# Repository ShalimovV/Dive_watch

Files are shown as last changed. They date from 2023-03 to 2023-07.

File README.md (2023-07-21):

# Dive_watch
DIY dive computer project for free diving

KiCAD project - https://github.com/ShalimovV/Dive_watch/tree/main/Hardware/d_watch_v2

Source code are here - https://github.com/ShalimovV/d_watch_v2_wb55

Youtube - https://www.youtube.com/@ShalimovProjects

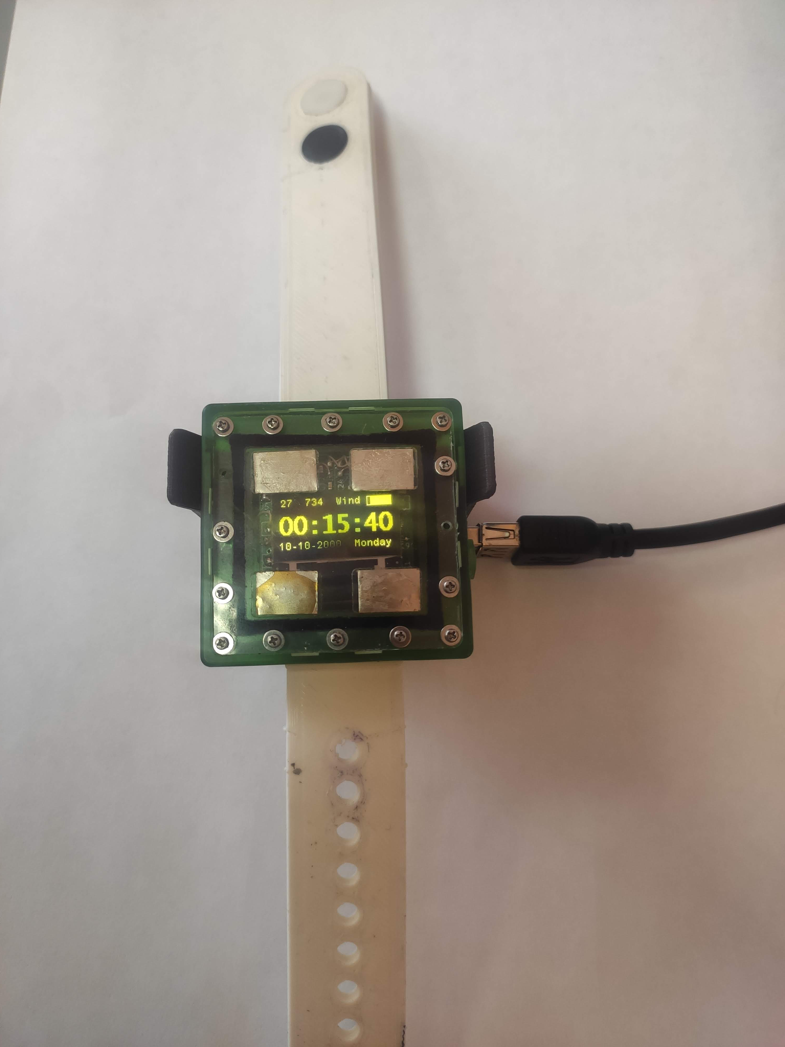
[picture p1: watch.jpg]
Watch


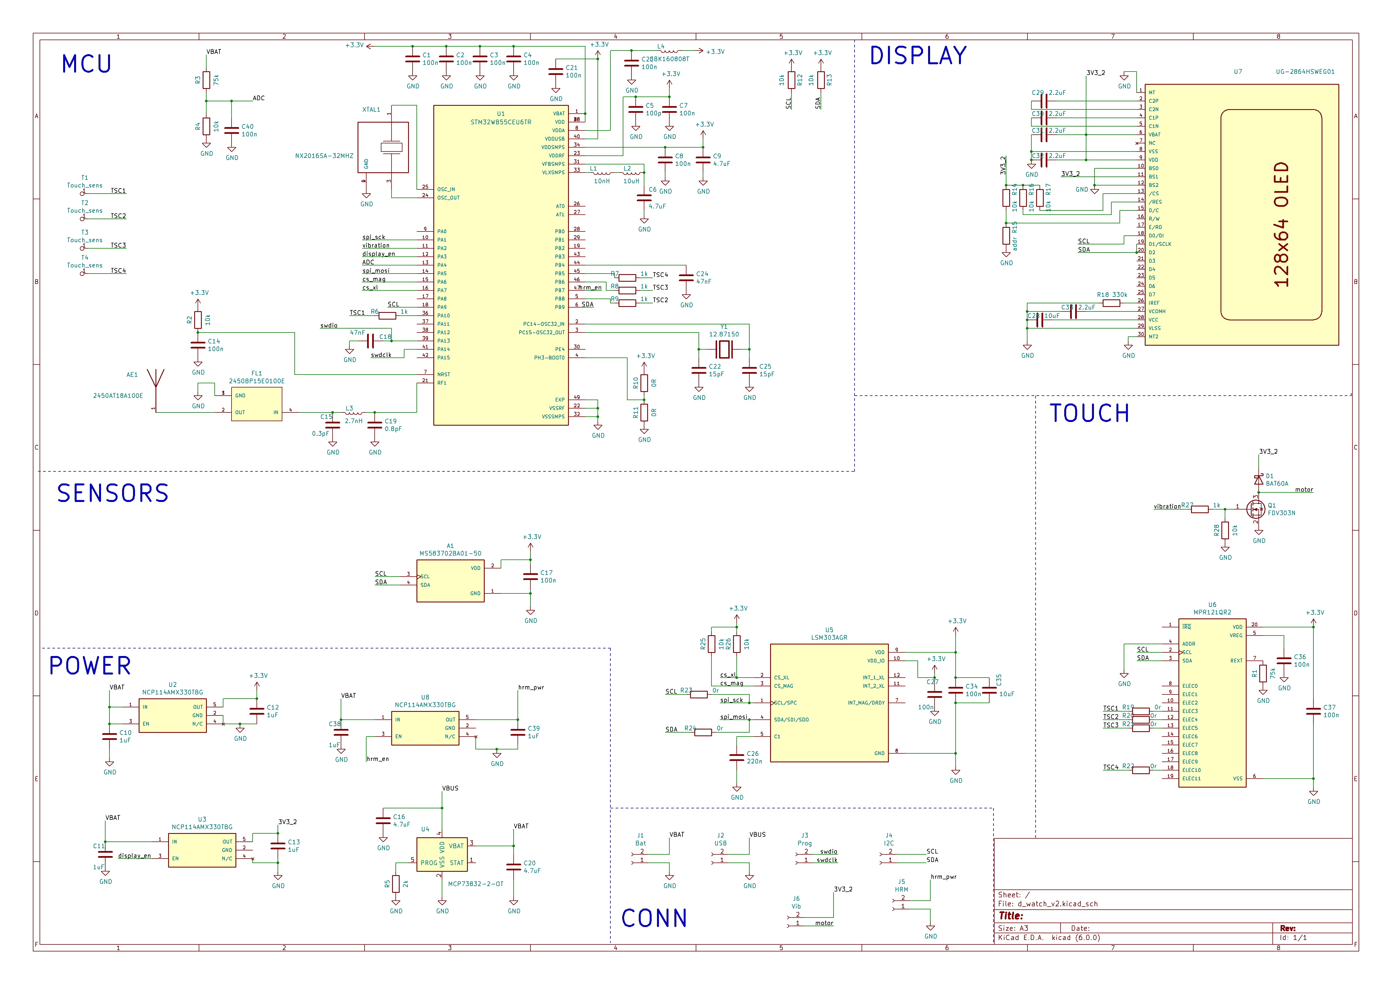
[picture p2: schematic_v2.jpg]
Schematics of watch


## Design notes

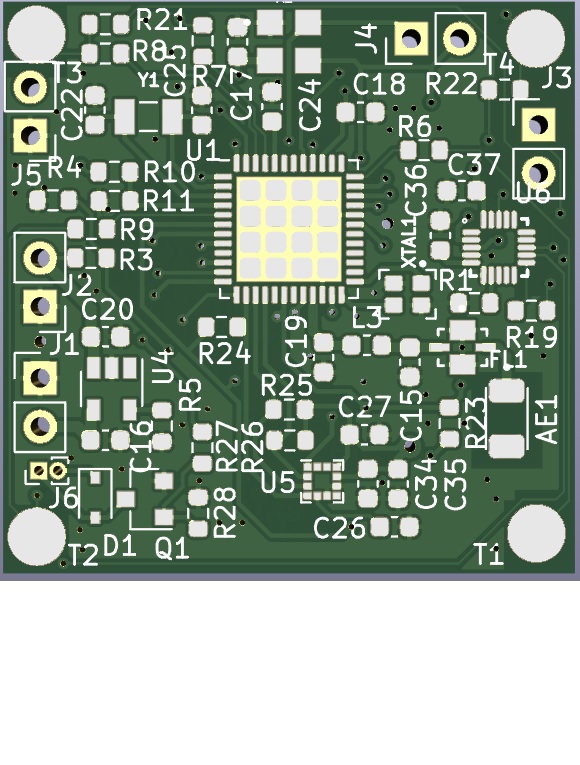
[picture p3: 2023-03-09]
pcb.jpg

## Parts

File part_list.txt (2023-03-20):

				IC
STM32WB55CGU6		UFQFPN48 7x7mm		1pcs		https://aliexpress.ru/item/1005002719693857.html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
MS5837									1pcs		https://aliexpress.ru/item/32965750576.html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
MPR121				QFN20				1pcs		https://aliexpress.ru/item/32821362153.html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
LSM303AGR			LGA-12				1pcs
MCP73831			SOT23-5				1pcs		https://aliexpress.ru/item/32825743634.html?spm=a2g2w.orderdetail.0.0.4e324aa6s5AVtw&sku_id=64850715808
NCP114AMX330T		SOT23-5				3pcs						
Display				128x64OLED			1pcs		https://aliexpress.ru/item/32830523451.html?sku_id=66632198948&spm=.search_results.0.50534aa68fm6GY

			Transistors
2N7002				SOT23				1pcs		https://aliexpress.ru/item/32475575705.html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

			Diode
BAT60A				SOD-323				1pcs		https://aliexpress.ru/item/32962432486.html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

			Resistors								https://aliexpress.ru/item/32773409942.html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
10k					R0603				9pcs
0R					R0603				8pcs
75k					R0603				1pcs
330k				R0603				2pcs
2k					R0603				1pcs
1k					R0603				4pcs
4k7					R0603				4pcs

			Capcitors								https://aliexpress.ru/item/4001345918046.html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
100n				C0603				15pcs
10uF				C0603				2pcs
220n				C0603				1pcs
100p				C0603				1pcs
12.5p				C0603				2pcs
4.7uF				C0603				4pcs
1uF					C0603				4pcs
0.3pF				C0603				1pcs
47nF				C0603				2pcs
0.8pF				C0603				1pcs
2.2uF				C0603				5pcs

			Inductions								https://aliexpress.ru/item/32855637642.html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
10nH				L0603				1pcs
10mH				L0603				1pcs
GBK160808T			L0603				1pcs
2.7nH				L0603				1pcs
2450BP15E0100E							1pcs		https://aliexpress.ru/item/32815857347.html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

			Crystal resonators
32768Hz				XTAL_12.87150		1pcs		https://aliexpress.ru/item/32991925425.html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
NX2016SA-32MHZ		OSCCC200X160X50N	1pcs		https://aliexpress.ru/item/1005002427704043.html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

Chip antenna		2450AT18A100E		1pcs		https://aliexpress.ru/item/4000604209164.html?spm=a2g2w.detail.pers_rcmd.9.141e5b12oDna1O&_evo_buckets=165609,165598,194275&sku_id=10000003837091303&gps-id=pcDetailBottomMoreOtherSeller&scm=1007.14452.331080.0&scm_id=1007.14452.331080.0&scm-url=1007.14452.331080.0&pvid=492aa6b8-92af-4c68-9dc5-84e5a704b253&_t=gps-id:pcDetailBottomMoreOtherSeller,scm-url:1007.14452.331080.0,pvid:492aa6b8-92af-4c68-9dc5-84e5a704b253,tpp_buckets:4452%230%23331080%230_4452%233474%2315675%23136_4452%234862%2324463%23909_4452%233098%239599%23202_4452%235105%2323438%23899_4452%233564%2316062%23650_21387%230%23330480%232_21387%239507%23434562%237_21387%2314793%23456925%234_24525%230%23331148%2318

Vibro motor								1pcs		https://aliexpress.ru/item/4000002321519.html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

Wire												https://aliexpress.ru/item/1005001386328055.html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

Li-Ion Battery										https://aliexpress.ru/item/4001240958438.html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

Rivets												https://aliexpress.ru/item/32998928980.html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

Test pin											https://aliexpress.ru/item/33004747616.html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

Nickel Sheet Plate	8mm								https://aliexpress.ru/item/1005004371792191.html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

ST-Link V2											https://aliexpress.ru/item/32792513237.html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

Screws M1.4x10			16pcs						https://aliexpress.ru/item/10000181324125.html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

Brass insert nut M1.4	16pcs						https://aliexpress.ru/item/1005002181788783.html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,165598,194275&sku_id=12000018969492937&gps-id=pcDetailBottomMoreOtherSeller&scm=1007.34525.331148.0&scm_id=1007.34525.331148.0&scm-url=1007.34525.331148.0&pvid=f5fdbbbf-246d-4539-a032-dc8f5a3d2d5d&_t=gps-id:pcDetailBottomMoreOtherSeller,scm-url:1007.34525.331148.0,pvid:f5fdbbbf-246d-4539-a032-dc8f5a3d2d5d,tpp_buckets:24525%230%23331148%2318_21387%230%23330480%231_21387%239507%23434562%237_21387%2314793%23456925%234_4452%230%23331080%230_4452%233474%2315675%23136_4452%234862%2324463%23909_4452%233098%239599%23202_4452%235105%2323438%23899_4452%233564%2316062%23650&ru_algo_pv_id=f5fdbbbf-246d-4539-a032-dc8f5a3d2d5d&scenario=pcDetailBottomMoreOtherSeller&tpp_rcmd_bucket_id=331148&traffic_source=recommendation

Washer 2mm				16pcs						https://aliexpress.ru/item/32975752411.html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

Acrylic Sheet 			3mm							https://aliexpress.ru/item/32833660352.html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

Rubber Sheet			3mm							https://aliexpress.ru/item/20000002492440.html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
	
Sealer (shaper pads) Victor Reinz 703141410			https://aliexpress.ru/item/1005004584983004.html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

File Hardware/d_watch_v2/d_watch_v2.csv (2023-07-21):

Source: | \\10.97.63.1\c$\Users\shalimov\Dropbox\Work\projects\diving watch\d_watch_v2\d_watch_v2\d_watch_v2.sch
Date: | 14.01.2022 15:19:52
Tool: | Eeschema (5.1.12)-1
Generator: | C:\Program Files\KiCad\bin\scripting\plugins/bom_csv_grouped_by_value.py
Component Count: | 99
Individual Components:
Item | Qty | Reference(s) | Value | LibPart | Footprint | Datasheet | AVAILABILITY | Availability | Comment | DESCRIPTION | Description | MANUFACTURER | MAXIMUM_PACKAGE_HEIGHT | MF | MP | PACKAGE | PARTREV | PRICE | PURCHASE-URL | Package | Price | Purchase-URL | STANDARD
 |  | A1 | MS583702BA01-50 | d_watch_v2-rescue:MS583702BA01-50-MS583702BA01-50 | XDCR_MS583702BA01-50 |  |  |  | MS583702BA01-50
 |  | AE1 | 2450AT18A100E | d_watch_v2-rescue:2450AT18A100E-2450AT18A100E | ANTC3216X140N |  |  |  |  |  |  | JOHANSON DESIGN |  |  |  |  | 1.3 |  |  |  |  |  | IPC-7351B
 |  | C1 | 100n | Device:C | Capacitor_SMD:C_0603_1608Metric | ~
 |  | C2 | 100n | Device:C | Capacitor_SMD:C_0603_1608Metric | ~
 |  | C3 | 100n | Device:C | Capacitor_SMD:C_0603_1608Metric | ~
 |  | C4 | 100n | Device:C | Capacitor_SMD:C_0603_1608Metric | ~
 |  | C5 | 100p | Device:C | Capacitor_SMD:C_0603_1608Metric | ~
 |  | C6 | 4.7uF | Device:C | Capacitor_SMD:C_0603_1608Metric | ~
 |  | C7 | 100n | Device:C | Capacitor_SMD:C_0603_1608Metric | ~
 |  | C8 | 100n | Device:C | Capacitor_SMD:C_0603_1608Metric | ~
 |  | C9 | 4.7uF | Device:C | Capacitor_SMD:C_0603_1608Metric | ~
 |  | C10 | 1uF | Device:C | Capacitor_SMD:C_0603_1608Metric | ~
 |  | C11 | 1uF | Device:C | Capacitor_SMD:C_0603_1608Metric | ~
 |  | C12 | 1uF | Device:C | Capacitor_SMD:C_0603_1608Metric | ~
 |  | C13 | 1uF | Device:C | Capacitor_SMD:C_0603_1608Metric | ~
 |  | C14 | 100n | Device:C | Capacitor_SMD:C_0603_1608Metric | ~
 |  | C15 | 0.3pF | Device:C | Capacitor_SMD:C_0603_1608Metric | ~
 |  | C16 | 4.7uF | Device:C | Capacitor_SMD:C_0603_1608Metric | ~
 |  | C17 | 100n | Device:C | Capacitor_SMD:C_0603_1608Metric | ~
 |  | C18 | 47nF | Device:C | Capacitor_SMD:C_0603_1608Metric | ~
 |  | C19 | 0.8pF | Device:C | Capacitor_SMD:C_0603_1608Metric | ~
 |  | C20 | 4.7uF | Device:C | Capacitor_SMD:C_0603_1608Metric | ~
 |  | C21 | 100n | Device:C | Capacitor_SMD:C_0603_1608Metric | ~
 |  | C22 | 15pF | Device:C | Capacitor_SMD:C_0603_1608Metric | ~
 |  | C23 | 100n | Device:C | Capacitor_SMD:C_0603_1608Metric | ~
 |  | C24 | 47nF | Device:C | Capacitor_SMD:C_0603_1608Metric | ~
 |  | C25 | 15pF | Device:C | Capacitor_SMD:C_0603_1608Metric | ~
 |  | C26 | 220n | Device:C | Capacitor_SMD:C_0603_1608Metric | ~
 |  | C27 | 100n | Device:C | Capacitor_SMD:C_0603_1608Metric | ~
 |  | C28 | 10uF | Device:C | Capacitor_SMD:C_0603_1608Metric | ~
 |  | C29 | 2.2uF | Device:C | Capacitor_SMD:C_0603_1608Metric | ~
 |  | C30 | 2.2uF | Device:C | Capacitor_SMD:C_0603_1608Metric | ~
 |  | C31 | 2.2uF | Device:C | Capacitor_SMD:C_0603_1608Metric | ~
 |  | C32 | 2.2uF | Device:C | Capacitor_SMD:C_0603_1608Metric | ~
 |  | C33 | 2.2uF | Device:C | Capacitor_SMD:C_0603_1608Metric | ~
 |  | C34 | 100n | Device:C | Capacitor_SMD:C_0603_1608Metric | ~
 |  | C35 | 10uF | Device:C | Capacitor_SMD:C_0603_1608Metric | ~
 |  | C36 | 100n | Device:C | Capacitor_SMD:C_0603_1608Metric | ~
 |  | C37 | 100n | Device:C | Capacitor_SMD:C_0603_1608Metric | ~
 |  | C38 | 1uF | Device:C | Capacitor_SMD:C_0603_1608Metric | ~
 |  | C39 | 1uF | Device:C | Capacitor_SMD:C_0603_1608Metric | ~
 |  | C40 | 100n | Device:C | Capacitor_SMD:C_0603_1608Metric | ~
 |  | C41 | 15pF | Device:C | Capacitor_SMD:C_0603_1608Metric | ~
 |  | C42 | 15pF | Device:C | Capacitor_SMD:C_0603_1608Metric | ~
 |  | D1 | BAT60A | Diode:BAT60A | Diode_SMD:D_SOD-323 | https://www.infineon.com/dgdl/Infineon-BAT60ASERIES-DS-v01_01-en.pdf?fileId=db3a304313d846880113def70c9304a9
 |  | FL1 | LFB212G45SG8C341 | d_watch_v2-rescue:LFB212G45SG8C341-LFB212G45SG8C341 | FIL_LFB212G45SG8C341 |  |  |  |  |  |  | Murata | 1.05 mm |  |  |  | N/A |  |  |  |  |  | Manufacturer recommendation
 |  | J1 | Conn_01x02 | Connector:Conn_01x02_Female | Connector_PinHeader_2.54mm:PinHeader_1x02_P2.54mm_Vertical | ~
 |  | J2 | Conn_01x02 | Connector:Conn_01x02_Female | Connector_PinHeader_2.54mm:PinHeader_1x02_P2.54mm_Vertical | ~
 |  | J3 | Conn_01x02 | Connector:Conn_01x02_Female | Connector_PinHeader_2.54mm:PinHeader_1x02_P2.54mm_Vertical | ~
 |  | J4 | Conn_01x02 | Connector:Conn_01x02_Female | Connector_PinHeader_2.54mm:PinHeader_1x02_P2.54mm_Vertical | ~
 |  | J5 | Conn_01x02 | Connector:Conn_01x02_Female | Connector_PinHeader_2.54mm:PinHeader_1x02_P2.54mm_Vertical | ~
 |  | J6 | Conn_01x02 | Connector:Conn_01x02_Female | Connector_PinHeader_1.00mm:PinHeader_1x02_P1.00mm_Vertical | ~
 |  | L1 | 10nH | Device:L | Inductor_SMD:L_0603_1608Metric | ~
 |  | L2 | 10mH | Device:L | Inductor_SMD:L_0603_1608Metric | ~
 |  | L3 | 2.7nH | Device:L | Inductor_SMD:L_0603_1608Metric | ~
 |  | L4 | GBK160808T | Device:L | Inductor_SMD:L_0603_1608Metric | ~
 |  | Q1 | FDV303N | Transistor_FET:2N7002K | Package_TO_SOT_SMD:SOT-23 | https://www.diodes.com/assets/Datasheets/ds30896.pdf
 |  | R1 | 75k | Device:R | Resistor_SMD:R_0603_1608Metric | ~
 |  | R2 | 10k | Device:R | Resistor_SMD:R_0603_1608Metric | ~
 |  | R3 | 330k | Device:R | Resistor_SMD:R_0603_1608Metric | ~
 |  | R4 | 10k | Device:R | Resistor_SMD:R_0603_1608Metric | ~
 |  | R5 | 2k | Device:R | Resistor_SMD:R_0603_1608Metric | ~
 |  | R6 | 1k | Device:R | Resistor_SMD:R_0603_1608Metric | ~
 |  | R7 | 1k | Device:R | Resistor_SMD:R_0603_1608Metric | ~
 |  | R8 | 1k | Device:R | Resistor_SMD:R_0603_1608Metric | ~
 |  | R9 | 1k | Device:R | Resistor_SMD:R_0603_1608Metric | ~
 |  | R10 | 0R | Device:R | Resistor_SMD:R_0603_1608Metric | ~
 |  | R11 | 0R | Device:R | Resistor_SMD:R_0603_1608Metric | ~
 |  | R12 | 10k | Device:R | Resistor_SMD:R_0603_1608Metric | ~
 |  | R13 | 10k | Device:R | Resistor_SMD:R_0603_1608Metric | ~
 |  | R14 | 10k | Device:R | Resistor_SMD:R_0603_1608Metric | ~
 |  | R15 | addr | Device:R | Resistor_SMD:R_0603_1608Metric | ~
 |  | R16 | 10k | Device:R | Resistor_SMD:R_0603_1608Metric | ~
 |  | R17 | 10k | Device:R | Resistor_SMD:R_0603_1608Metric | ~
 |  | R18 | 330k | Device:R | Resistor_SMD:R_0603_1608Metric | ~
 |  | R19 | 0r | Device:R | Resistor_SMD:R_0603_1608Metric | ~
 |  | R20 | 0r | Device:R | Resistor_SMD:R_0603_1608Metric | ~
 |  | R21 | 0r | Device:R | Resistor_SMD:R_0603_1608Metric | ~
 |  | R22 | 0r | Device:R | Resistor_SMD:R_0603_1608Metric | ~
 |  | R23 | 0r | Device:R | Resistor_SMD:R_0603_1608Metric | ~
 |  | R24 | 0r | Device:R | Resistor_SMD:R_0603_1608Metric | ~
 |  | R25 | 10k | Device:R | Resistor_SMD:R_0603_1608Metric | ~
 |  | R26 | 10k | Device:R | Resistor_SMD:R_0603_1608Metric | ~
 |  | R27 | 1k | Device:R | Resistor_SMD:R_0603_1608Metric | ~
 |  | R28 | 10k | Device:R | Resistor_SMD:R_0603_1608Metric | ~
 |  | T1 | Touch_sens | d_watch_v2-rescue:Touch_sens-touch_sens | Sensor:touch_pad
 |  | T2 | Touch_sens | d_watch_v2-rescue:Touch_sens-touch_sens | Sensor:touch_pad
 |  | T3 | Touch_sens | d_watch_v2-rescue:Touch_sens-touch_sens | Sensor:touch_pad
 |  | T4 | Touch_sens | d_watch_v2-rescue:Touch_sens-touch_sens | Sensor:touch_pad
 |  | U1 | STM32WB55CEU6TR | d_watch_v2-rescue:STM32WB55CEU6TR-STM32WB55CEU6TR | Package_DFN_QFN:QFN-48-1EP_7x7mm_P0.5mm_EP5.45x5.45mm |  |  |  |  |  |  | STMicroelectronics | 0.6 mm |  |  |  | 5 |  |  |  |  |  | IPC 7351B
 |  | U4 | MCP73832-2-OT | Battery_Management:MCP73832-2-OT | Package_TO_SOT_SMD:SOT-23-5 | http://ww1.microchip.com/downloads/en/DeviceDoc/20001984g.pdf
 |  | U5 | LSM303AGR | d_watch_v2-rescue:LSM303AGR-LSM303AGR | Package_LGA:LGA-12_2x2mm_P0.5mm |  |  | In Stock |  |  | \nAccelerometer, Magnetometer, Temperature, 6 Axis Sensor I²C, SPI Output\n |  |  | STMicroelectronics | LSM303AGR |  |  |  |  | VFLGA-12 STMicroelectronics | None | https://pricing.snapeda.com/search/part/LSM303AGR/?ref=eda
 |  | U6 | MPR121QR2 | d_watch_v2-rescue:MPR121QR2-MPR121QR2 | QFN40P300X300X60-20N |  |  |  |  |  |  | Freescale NXP
 |  | U7 | UG-2864HSWEG01 | d_watch_v2-rescue:UG-2864HSWEG01-UG-2864HSWEG01 | 1X30-0.7MM
 |  | VR1 | TLV707185DQNR | d_watch_v2-rescue:TLV707185DQNR-TLV707185DQNR | VREG_TLV707185DQNR |  | Warning |  |  | 200-mA, low-IQ, low-dropout voltage regulator with enable 4-X2SON -40 to 125 |  |  |  | Texas Instruments | TLV707185DQNR | X2SON-4 Texas Instruments |  | None | https://pricing.snapeda.com/search/part/TLV707185DQNR/?ref=eda
 |  | VR2 | TLV707185DQNR | d_watch_v2-rescue:TLV707185DQNR-TLV707185DQNR | VREG_TLV707185DQNR |  | Warning |  |  | 200-mA, low-IQ, low-dropout voltage regulator with enable 4-X2SON -40 to 125 |  |  |  | Texas Instruments | TLV707185DQNR | X2SON-4 Texas Instruments |  | None | https://pricing.snapeda.com/search/part/TLV707185DQNR/?ref=eda
 |  | VR3 | TLV707185DQNR | d_watch_v2-rescue:TLV707185DQNR-TLV707185DQNR | VREG_TLV707185DQNR |  | Warning |  |  | 200-mA, low-IQ, low-dropout voltage regulator with enable 4-X2SON -40 to 125 |  |  |  | Texas Instruments | TLV707185DQNR | X2SON-4 Texas Instruments |  | None | https://pricing.snapeda.com/search/part/TLV707185DQNR/?ref=eda
 |  | XTAL1 | NX2016SA-32MHZ | d_watch_v2-rescue:NX2016SA-52MHZ-EXS00A-CS07103-NX2016SA-52MHZ-EXS00A-CS07103 | OSCCC200X160X50N |  |  |  |  |  |  | NDK |  |  |  |  | N/A |  |  |  |  |  | IPC-7351B
 |  | Y1 | 12.87150 | d_watch_v2-rescue:12.87150-12.87150 | XTAL_12.87150 |  |  |  |  |  |  | Geyer Electronic | 0.9mm |  |  |  | 22.06.2021 |  |  |  |  |  | Manufacturer Recommendations
Collated Components:
Item | Qty | Reference(s) | Value | LibPart | Footprint | Datasheet | AVAILABILITY | Availability | Comment | DESCRIPTION | Description | MANUFACTURER | MAXIMUM_PACKAGE_HEIGHT | MF | MP | PACKAGE | PARTREV | PRICE | PURCHASE-URL | Package | Price | Purchase-URL | STANDARD
1 | 1 | A1 | MS583702BA01-50 | d_watch_v2-rescue:MS583702BA01-50-MS583702BA01-50 | XDCR_MS583702BA01-50 |  |  |  | MS583702BA01-50
2 | 1 | AE1 | 2450AT18A100E | d_watch_v2-rescue:2450AT18A100E-2450AT18A100E | ANTC3216X140N |  |  |  |  |  |  | JOHANSON DESIGN |  |  |  |  | 1.3 |  |  |  |  |  | IPC-7351B
3 | 15 | C1, C2, C3, C4, C7, C8, C14, C17, C21, C23, C27, C34, C36, C37, C40 | 100n | Device:C | Capacitor_SMD:C_0603_1608Metric | ~
4 | 1 | C5 | 100p | Device:C | Capacitor_SMD:C_0603_1608Metric | ~
5 | 4 | C6, C9, C16, C20 | 4.7uF | Device:C | Capacitor_SMD:C_0603_1608Metric | ~
6 | 6 | C10, C11, C12, C13, C38, C39 | 1uF | Device:C | Capacitor_SMD:C_0603_1608Metric | ~
7 | 1 | C15 | 0.3pF | Device:C | Capacitor_SMD:C_0603_1608Metric | ~
8 | 2 | C18, C24 | 47nF | Device:C | Capacitor_SMD:C_0603_1608Metric | ~
9 | 1 | C19 | 0.8pF | Device:C | Capacitor_SMD:C_0603_1608Metric | ~
10 | 4 | C22, C25, C41, C42 | 15pF | Device:C | Capacitor_SMD:C_0603_1608Metric | ~
11 | 1 | C26 | 220n | Device:C | Capacitor_SMD:C_0603_1608Metric | ~
12 | 2 | C28, C35 | 10uF | Device:C | Capacitor_SMD:C_0603_1608Metric | ~
13 | 5 | C29, C30, C31, C32, C33 | 2.2uF | Device:C | Capacitor_SMD:C_0603_1608Metric | ~
14 | 1 | D1 | BAT60A | Diode:BAT60A | Diode_SMD:D_SOD-323 | https://www.infineon.com/dgdl/Infineon-BAT60ASERIES-DS-v01_01-en.pdf?fileId=db3a304313d846880113def70c9304a9
15 | 1 | FL1 | LFB212G45SG8C341 | d_watch_v2-rescue:LFB212G45SG8C341-LFB212G45SG8C341 | FIL_LFB212G45SG8C341 |  |  |  |  |  |  | Murata | 1.05 mm |  |  |  | N/A |  |  |  |  |  | Manufacturer recommendation
16 | 5 | J1, J2, J3, J4, J5 | Conn_01x02 | Connector:Conn_01x02_Female | Connector_PinHeader_2.54mm:PinHeader_1x02_P2.54mm_Vertical | ~
17 | 1 | J6 | Conn_01x02 | Connector:Conn_01x02_Female | Connector_PinHeader_1.00mm:PinHeader_1x02_P1.00mm_Vertical | ~
18 | 1 | L1 | 10nH | Device:L | Inductor_SMD:L_0603_1608Metric | ~
19 | 1 | L2 | 10mH | Device:L | Inductor_SMD:L_0603_1608Metric | ~
20 | 1 | L3 | 2.7nH | Device:L | Inductor_SMD:L_0603_1608Metric | ~
21 | 1 | L4 | GBK160808T | Device:L | Inductor_SMD:L_0603_1608Metric | ~
22 | 1 | Q1 | FDV303N | Transistor_FET:2N7002K | Package_TO_SOT_SMD:SOT-23 | https://www.diodes.com/assets/Datasheets/ds30896.pdf
23 | 1 | R1 | 75k | Device:R | Resistor_SMD:R_0603_1608Metric | ~
24 | 10 | R2, R4, R12, R13, R14, R16, R17, R25, R26, R28 | 10k | Device:R | Resistor_SMD:R_0603_1608Metric | ~
25 | 2 | R3, R18 | 330k | Device:R | Resistor_SMD:R_0603_1608Metric | ~
26 | 1 | R5 | 2k | Device:R | Resistor_SMD:R_0603_1608Metric | ~
27 | 5 | R6, R7, R8, R9, R27 | 1k | Device:R | Resistor_SMD:R_0603_1608Metric | ~
28 | 2 | R10, R11 | 0R | Device:R | Resistor_SMD:R_0603_1608Metric | ~
29 | 1 | R15 | addr | Device:R | Resistor_SMD:R_0603_1608Metric | ~
30 | 6 | R19, R20, R21, R22, R23, R24 | 0r | Device:R | Resistor_SMD:R_0603_1608Metric | ~
31 | 4 | T1, T2, T3, T4 | Touch_sens | d_watch_v2-rescue:Touch_sens-touch_sens | Sensor:touch_pad
32 | 1 | U1 | STM32WB55CEU6TR | d_watch_v2-rescue:STM32WB55CEU6TR-STM32WB55CEU6TR | Package_DFN_QFN:QFN-48-1EP_7x7mm_P0.5mm_EP5.45x5.45mm |  |  |  |  |  |  | STMicroelectronics | 0.6 mm |  |  |  | 5 |  |  |  |  |  | IPC 7351B
33 | 1 | U4 | MCP73832-2-OT | Battery_Management:MCP73832-2-OT | Package_TO_SOT_SMD:SOT-23-5 | http://ww1.microchip.com/downloads/en/DeviceDoc/20001984g.pdf
34 | 1 | U5 | LSM303AGR | d_watch_v2-rescue:LSM303AGR-LSM303AGR | Package_LGA:LGA-12_2x2mm_P0.5mm |  |  | In Stock |  |  | \nAccelerometer, Magnetometer, Temperature, 6 Axis Sensor I²C, SPI Output\n |  |  | STMicroelectronics | LSM303AGR |  |  |  |  | VFLGA-12 STMicroelectronics | None | https://pricing.snapeda.com/search/part/LSM303AGR/?ref=eda
35 | 1 | U6 | MPR121QR2 | d_watch_v2-rescue:MPR121QR2-MPR121QR2 | QFN40P300X300X60-20N |  |  |  |  |  |  | Freescale NXP
36 | 1 | U7 | UG-2864HSWEG01 | d_watch_v2-rescue:UG-2864HSWEG01-UG-2864HSWEG01 | 1X30-0.7MM
37 | 3 | VR1, VR2, VR3 | TLV707185DQNR | d_watch_v2-rescue:TLV707185DQNR-TLV707185DQNR | VREG_TLV707185DQNR |  | Warning |  |  | 200-mA, low-IQ, low-dropout voltage regulator with enable 4-X2SON -40 to 125 |  |  |  | Texas Instruments | TLV707185DQNR | X2SON-4 Texas Instruments |  | None | https://pricing.snapeda.com/search/part/TLV707185DQNR/?ref=eda
38 | 1 | XTAL1 | NX2016SA-32MHZ | d_watch_v2-rescue:NX2016SA-52MHZ-EXS00A-CS07103-NX2016SA-52MHZ-EXS00A-CS07103 | OSCCC200X160X50N |  |  |  |  |  |  | NDK |  |  |  |  | N/A |  |  |  |  |  | IPC-7351B
39 | 1 | Y1 | 12.87150 | d_watch_v2-rescue:12.87150-12.87150 | XTAL_12.87150 |  |  |  |  |  |  | Geyer Electronic | 0.9mm |  |  |  | 22.06.2021 |  |  |  |  |  | Manufacturer Recommendations

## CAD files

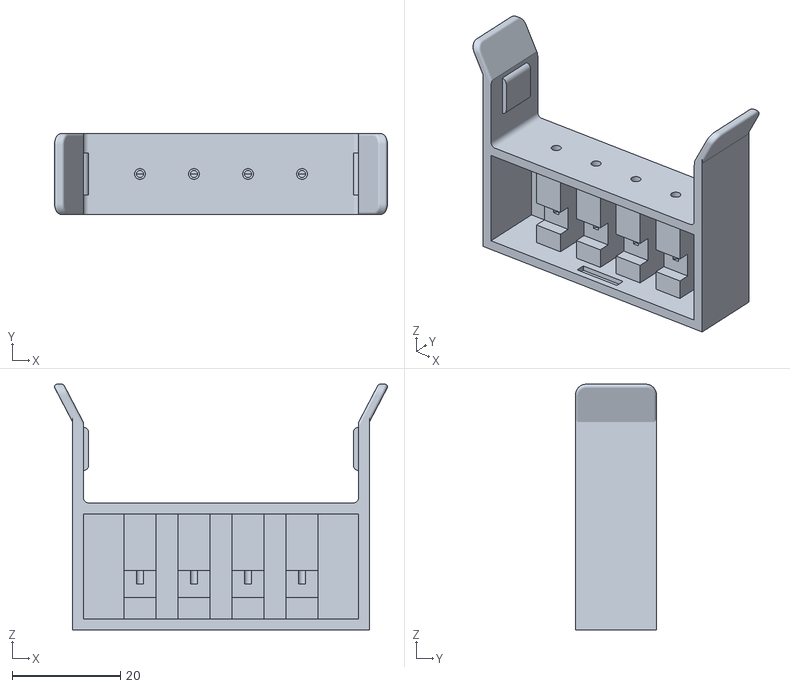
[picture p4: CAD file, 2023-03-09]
STL/charge_clipse_v2.STL
61.7 x 15.0 x 45.5

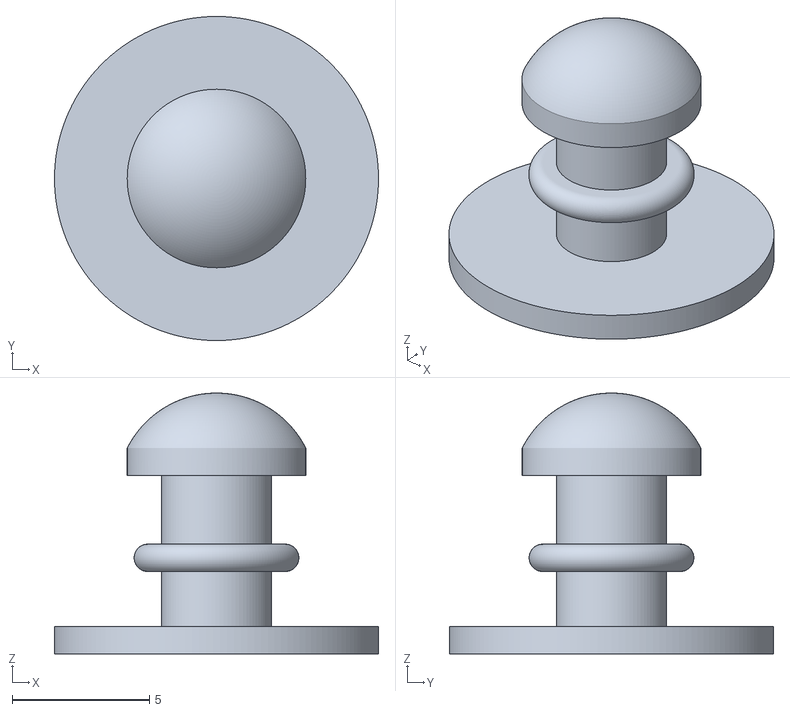
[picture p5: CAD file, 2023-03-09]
STL/pin.STL
11.8 x 11.8 x 9.50

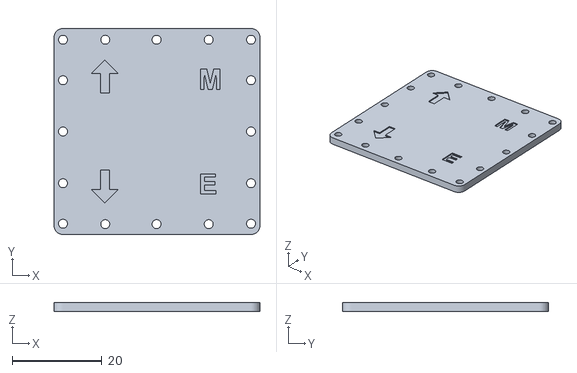
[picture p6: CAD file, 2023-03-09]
STL/glass.STL
45.8 x 45.8 x 2.00

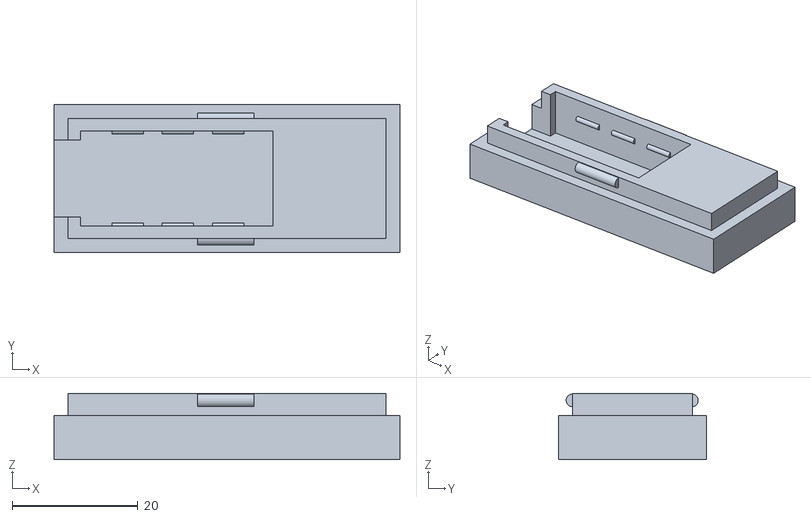
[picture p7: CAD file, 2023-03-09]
STL/charge_clipse_v2_cap.STL
55.0 x 23.5 x 10.5

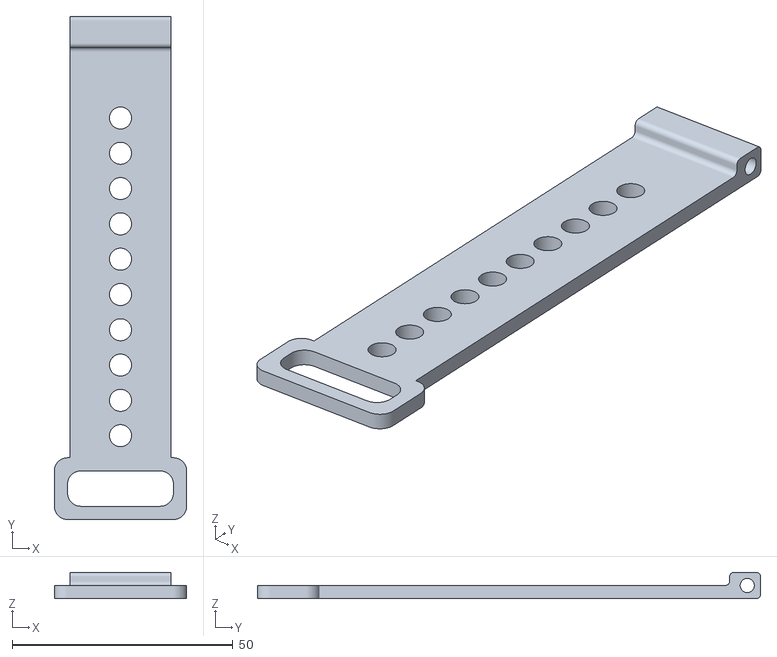
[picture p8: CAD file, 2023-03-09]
STL/belt2.STL
30.0 x 114.0 x 6.00

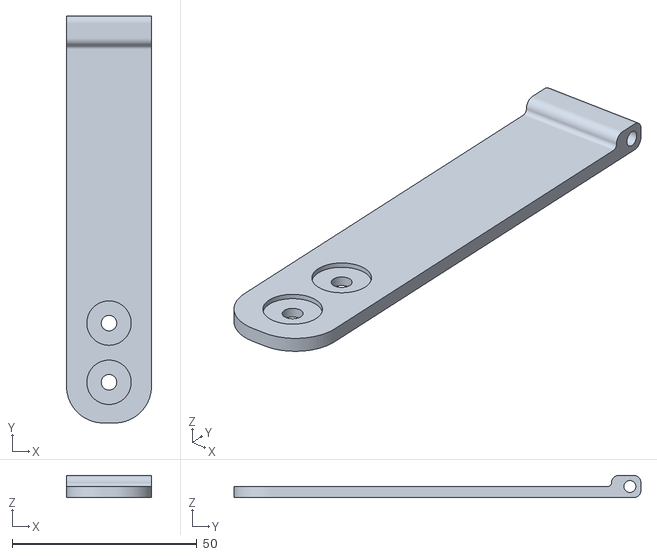
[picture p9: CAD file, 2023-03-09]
STL/belt1.STL
23.0 x 110.0 x 6.00

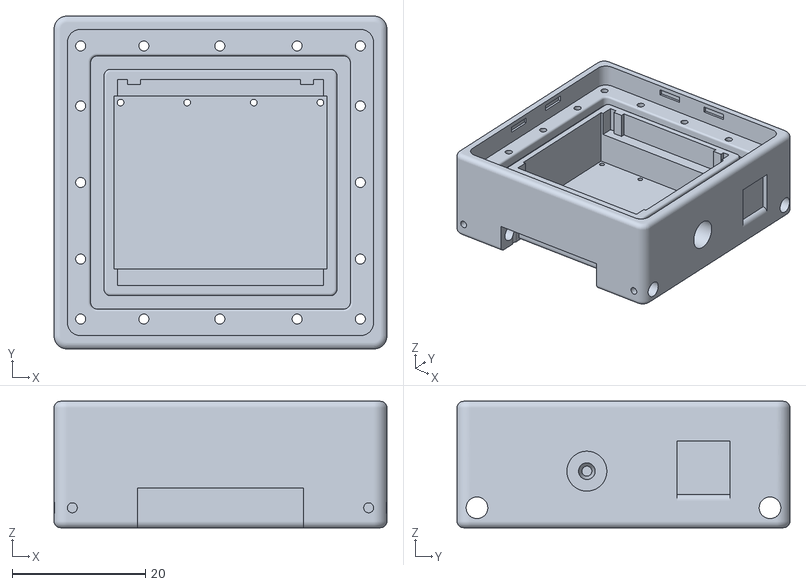
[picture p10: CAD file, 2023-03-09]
STL/case_v2.STL
50.0 x 50.0 x 19.0

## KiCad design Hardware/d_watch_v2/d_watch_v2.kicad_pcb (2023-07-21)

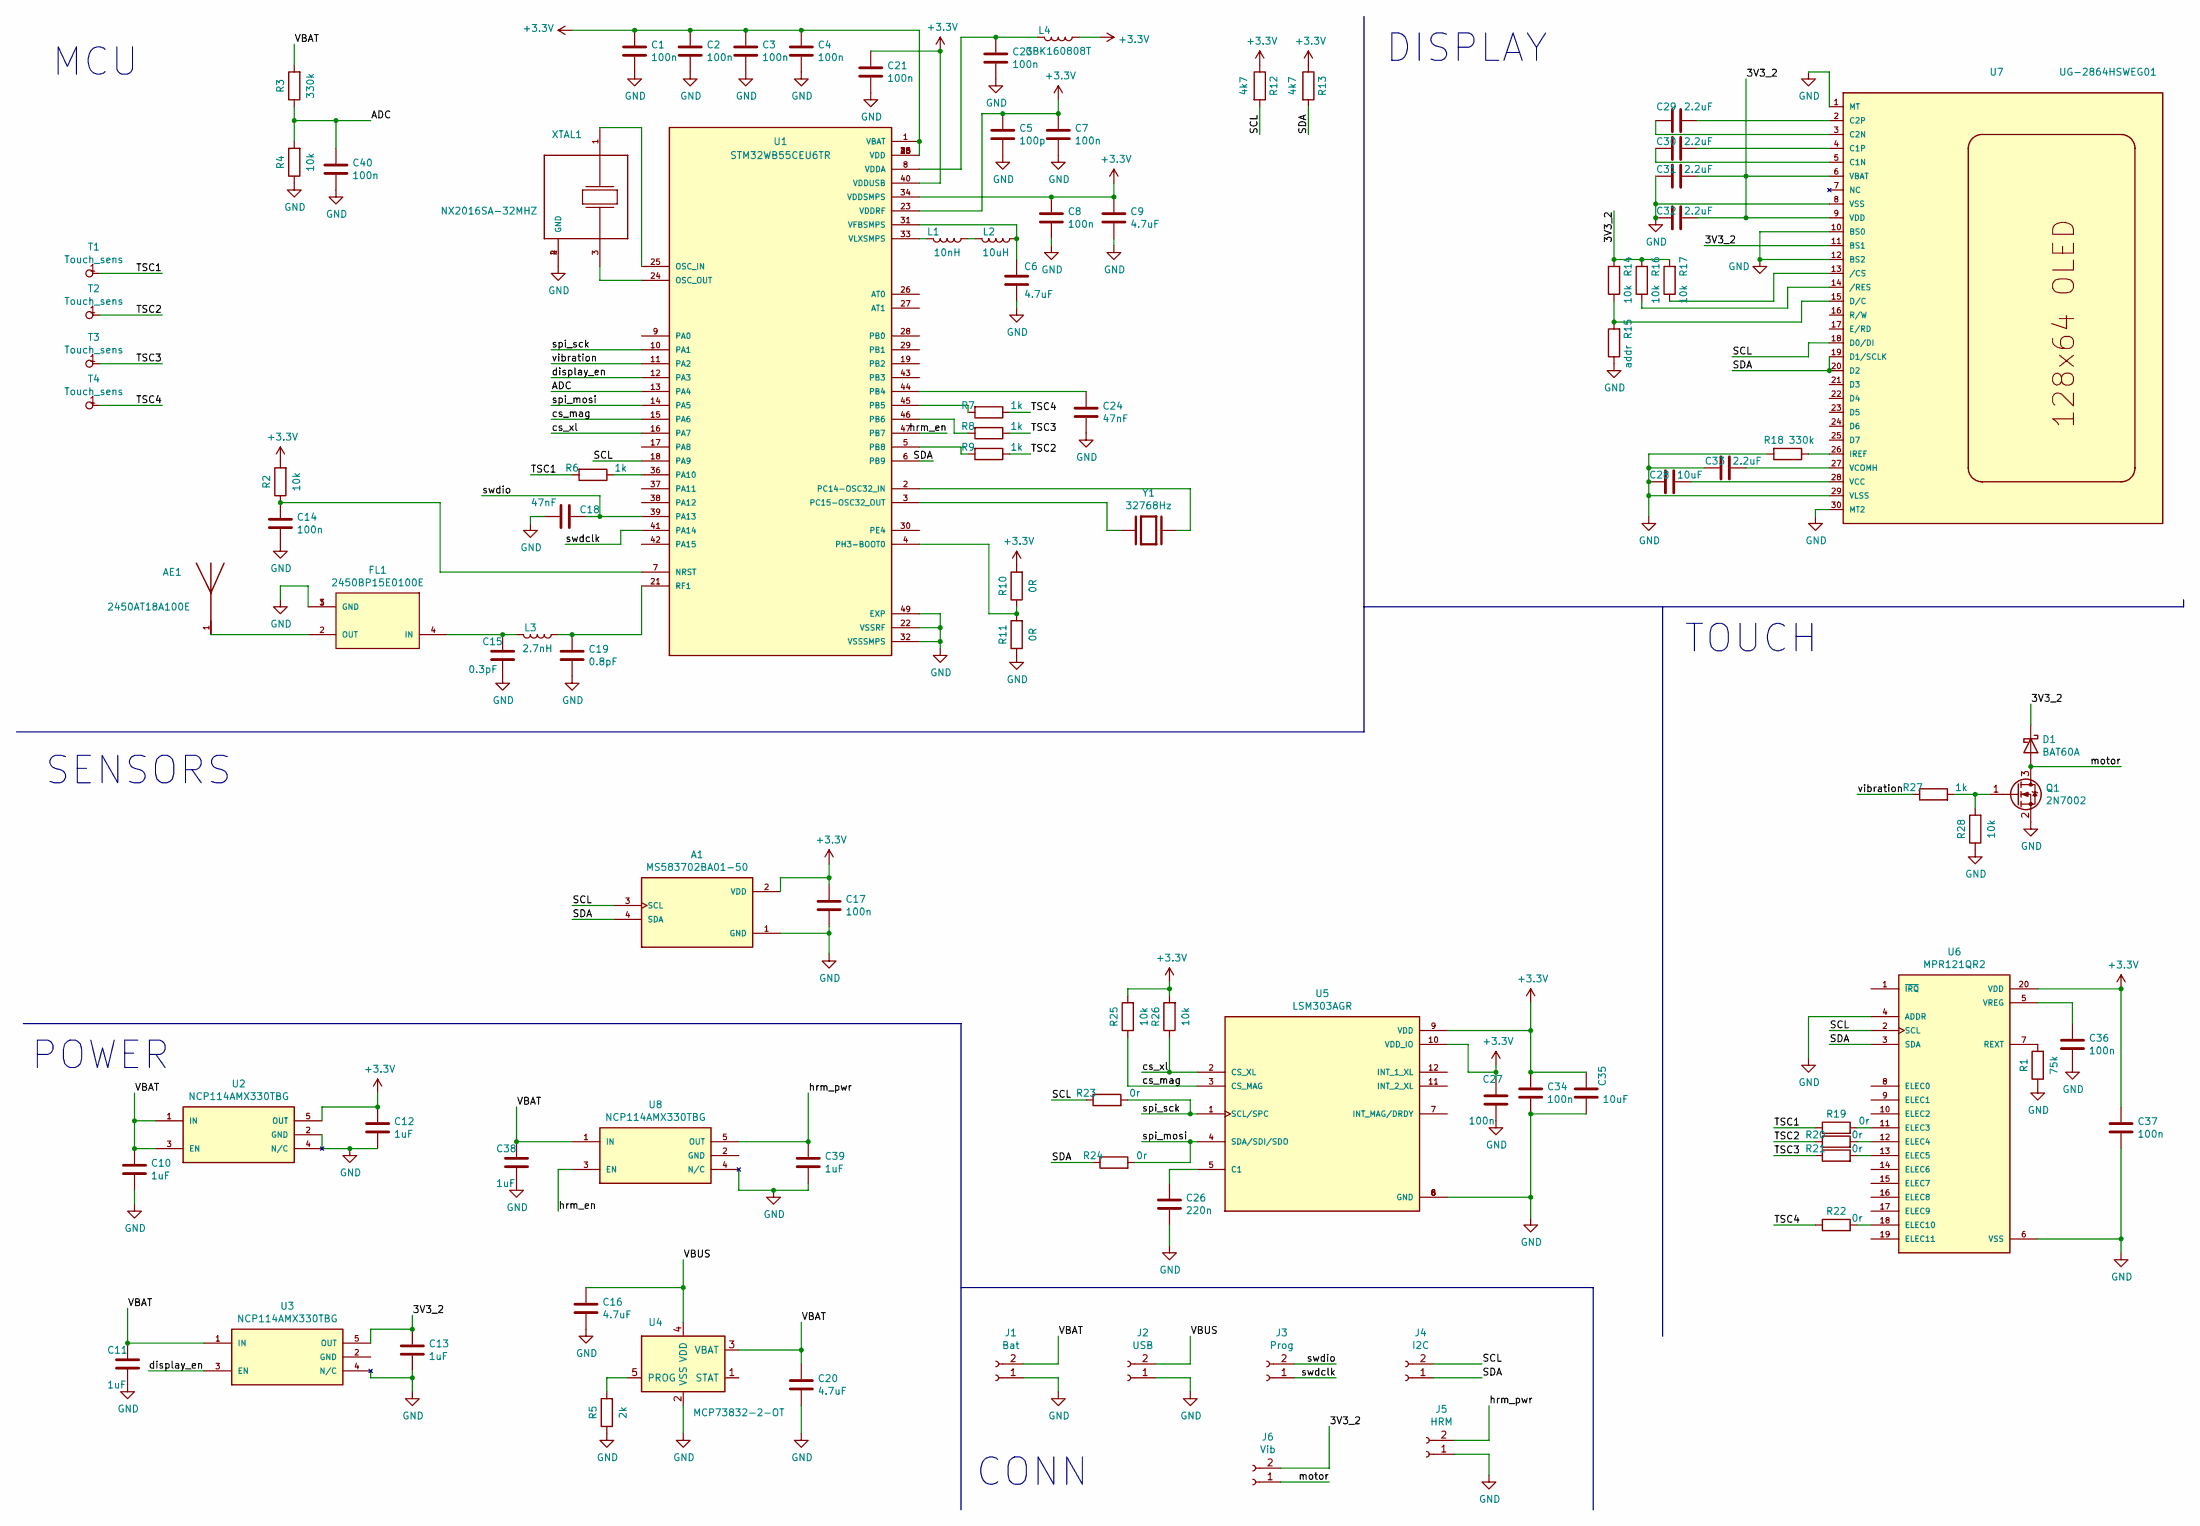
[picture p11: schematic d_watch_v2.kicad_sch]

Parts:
A1: MS583702BA01-50; XDCR_MS583702BA01-50
AE1: 2450AT18A100E; ANTC3216X140N; PARTREV 1.3
C1, C2, C3, C4, C7, C8, C14, C17, C21, C23, C27, C34, C36, C37, C40: 100n; C_0603_1608Metric
C5: 100p; C_0603_1608Metric
C6, C9, C16, C20: 4.7uF; C_0603_1608Metric
C10, C11, C12, C13, C38, C39: 1uF; C_0603_1608Metric
C15: 0.3pF; C_0603_1608Metric
C18, C24: 47nF; C_0603_1608Metric
C19: 0.8pF; C_0603_1608Metric
C26: 220n; C_0603_1608Metric
C28, C35: 10uF; C_0603_1608Metric
C29, C30, C31, C32, C33: 2.2uF; C_0603_1608Metric
D1: BAT60A; D_SOD-323
FL1: 2450BP15E0100E; FIL_2450BP15E0100E; PARTREV 1.0
J1: Bat; PinHeader_1x02_P2.54mm_Vertical
J2: USB; PinHeader_1x02_P2.54mm_Vertical
J3: Prog; PinHeader_1x02_P2.54mm_Vertical
J4: I2C; PinHeader_1x02_P2.54mm_Vertical
J5: HRM; PinHeader_1x02_P2.54mm_Vertical
J6: Vib; PinHeader_1x02_P1.00mm_Vertical
L1: 10nH; L_0603_1608Metric
L2: 10uH; L_0603_1608Metric
L3: 2.7nH; L_0603_1608Metric
L4: GBK160808T; L_0603_1608Metric
Q1: 2N7002; SOT-23
R1: 75k; R_0603_1608Metric
R2, R4, R14, R16, R17, R25, R26, R28: 10k; R_0603_1608Metric
R3, R18: 330k; R_0603_1608Metric
R5: 2k; R_0603_1608Metric
R6, R7, R8, R9, R27: 1k; R_0603_1608Metric
R10, R11: 0R; R_0603_1608Metric
R12, R13: 4k7; R_0603_1608Metric
R15: addr; R_0603_1608Metric
R19, R20, R21, R22, R23, R24: 0r; R_0603_1608Metric
T1, T2, T3, T4: Touch_sens; touch_pad
U1: STM32WB55CEU6TR; QFN-48-1EP_7x7mm_P0.5mm_EP5.45x5.45mm; PARTREV 5
U2, U3, U8: NCP114AMX330TBG; SOT-23-5
U4: MCP73832-2-OT; SOT-23-5
U5: LSM303AGR; LGA-12_2x2mm_P0.5mm
U6: MPR121QR2; QFN40P300X300X60-20N
U7: UG-2864HSWEG01; 1X30-0.7MM
XTAL1: NX2016SA-32MHZ; OSCCC200X160X50N; PARTREV N/A
Y1: 32768Hz; XTAL_12.87150; PARTREV 22.06.2021

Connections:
+3V3: A1.2 (VDD), C1.1, C2.1, C3.1, C4.1, C5.1, C7.1, C8.1, C9.1, C12.1, C17.1, C21.1, C27.1, C34.1, C35.1, C37.1, L4.1, R2.2, R10.2, R12.1, R13.1, R25.2, R26.2, U1.1 (VBAT), U1.20 (VDD), U1.23 (VDDRF), U1.34 (VDDSMPS), U1.35 (VDD), U1.40 (VDDUSB), U1.48 (VDD), U2.5 (OUT), U5.9 (VDD), U5.10 (VDD_IO), U6.20 (VDD)
/3V3_2: C13.1, C31.1, C32.1, D1.1 (K), J6.2, R14.2, R16.2, R17.2, U3.5 (OUT), U7.6 (VBAT), U7.9 (VDD), U7.11 (BS1)
/ADC: C40.1, R3.1, R4.2, U1.13 (PA4)
/SCL: A1.3 (SCL), J4.2, R12.2, R23.1, U1.18 (PA9), U6.2 (SCL), U7.18 (D0/DI)
/SDA: A1.4 (SDA), J4.1, R13.2, R24.1, U1.6 (PB9), U6.3 (SDA), U7.19 (D1/SCLK), U7.20 (D2)
/TSC1: R6.2, R19.1, T1.1
/TSC2: R9.1, R20.1, T2.1
/TSC3: R8.1, R21.1, T3.1
/TSC4: R7.1, R22.1, T4.1
/VBAT: C10.1, C11.1, C20.1, C38.1, J1.2, R3.2, U2.1 (IN), U2.3 (EN), U3.1 (IN), U4.3 (VBAT), U8.1 (IN)
/VBUS: C16.1, J2.2, U4.4 (VDD)
/cs_mag: R25.1, U1.15 (PA6), U5.3 (CS_MAG)
/cs_xl: R26.1, U1.16 (PA7), U5.2 (CS_XL)
/display_en: U1.12 (PA3), U3.3 (EN)
/hrm_en: U1.47 (PB7), U8.3 (EN)
/hrm_pwr: C39.1, J5.2, U8.5 (OUT)
/motor: D1.2 (A), J6.1, Q1.3 (D)
/spi_mosi: R24.2, U1.14 (PA5), U5.4 (SDA/SDI/SDO)
/spi_sck: R23.2, U1.10 (PA1), U5.1 (SCL/SPC)
/swdclk: J3.1, U1.41 (PA14)
/swdio: C18.1, J3.2, U1.39 (PA13)
/vibration: R27.1, U1.11 (PA2)
GND: A1.1 (GND), C1.2, C2.2, C3.2, C4.2, C5.2, C6.2, C7.2, C8.2, C9.2, C10.2, C11.2, C12.2, C13.2, C14.2, C15.2, C16.2, C17.2, C18.2, C19.2, C20.2, C21.2, C23.2, C24.2, C26.2, C27.2, C28.2, C31.2, C32.2, C33.2, C34.2, C35.2, C36.2, C37.2, C38.2, C39.2, C40.2, FL1.1 (GND), FL1.3 (GND), J1.1, J2.1, J5.1, Q1.2 (S), R1.1, R4.1, R5.1, R11.1, R15.1, R18.2, R28.1, U1.22 (VSSRF), U1.32 (VSSSMPS), U1.49 (EXP), U2.2 (GND), U2.4 (N/C), U3.4 (N/C), U4.2 (VSS), U5.6 (GND), U5.8 (GND), U6.4 (ADDR), U6.6 (VSS), U7.1 (MT), U7.8 (VSS), U7.10 (BS0), U7.12 (BS2), U7.29 (VLSS), U7.30 (MT2), U8.4 (N/C), XTAL1.2 (GND), XTAL1.4 (GND); also elsewhere on the board
unnamed: AE1.1, FL1.2 (OUT)
unnamed: C6.1, L2.1, U1.31 (VFBSMPS)
unnamed: C14.1, R2.1, U1.7 (NRST)
unnamed: C15.1, FL1.4 (IN), L3.2
unnamed: C19.1, L3.1, U1.21 (RF1)
unnamed 28: U1.3 (PC15-OSC32_OUT), Y1.1; also elsewhere on the board
unnamed: C23.1, L4.2, U1.8 (VDDA)
unnamed: C24.1, U1.44 (PB4)
unnamed 31: U1.2 (PC14-OSC32_IN), Y1.2; also elsewhere on the board
unnamed: C26.1, U5.5 (C1)
unnamed: C28.1, U7.28 (VCC)
unnamed: C29.1, U7.2 (C2P)
unnamed: C29.2, U7.3 (C2N)
unnamed: C30.1, U7.4 (C1P)
unnamed: C30.2, U7.5 (C1N)
unnamed: C33.1, U7.27 (VCOMH)
unnamed: C36.1, U6.5 (VREG)
unnamed: L1.1, L2.2
unnamed: L1.2, U1.33 (VLXSMPS)
unnamed: Q1.1 (G), R27.2, R28.2
unnamed: R1.2, U6.7 (REXT)
unnamed: R5.2, U4.5 (PROG)
unnamed: R6.1, U1.36 (PA10)
unnamed: R7.2, U1.45 (PB5)
unnamed: R8.2, U1.46 (PB6)
unnamed: R9.2, U1.5 (PB8)
unnamed: R10.1, R11.2, U1.4 (PH3-BOOT0)
unnamed: R14.1, R15.2, U7.15 (D/C)
unnamed: R16.1, U7.14 (/RES)
unnamed: R17.1, U7.13 (/CS)
unnamed: R18.1, U7.26 (IREF)
unnamed: R19.2, U6.11 (ELEC3)
unnamed: R20.2, U6.12 (ELEC4)
unnamed: R21.2, U6.13 (ELEC5)
unnamed: R22.2, U6.18 (ELEC10)
unnamed: U1.24 (OSC_OUT), XTAL1.3
unnamed: U1.25 (OSC_IN), XTAL1.1

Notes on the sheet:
SENSORS
DISPLAY
CONN
POWER
MCU
TOUCH

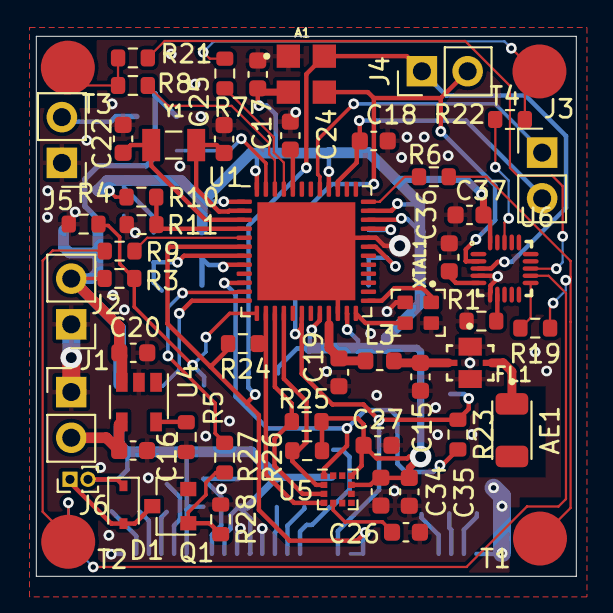
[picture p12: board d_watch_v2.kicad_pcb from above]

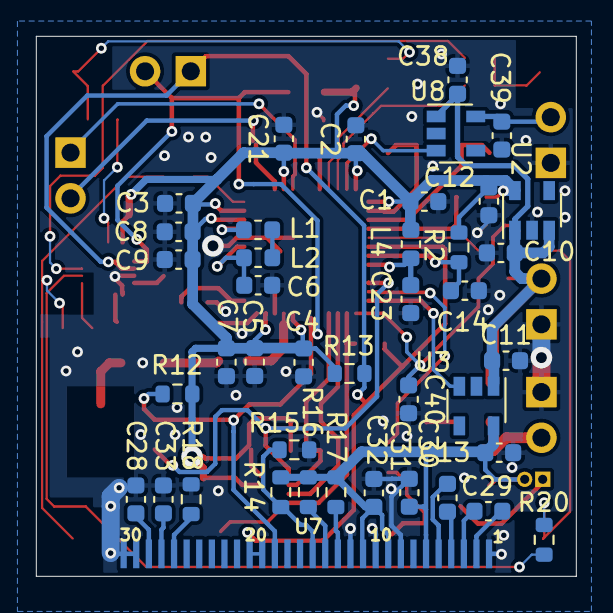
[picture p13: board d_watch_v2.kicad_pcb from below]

Board: 2 copper layers, 30.0 x 30.0 mm, 97 parts (41 on the bottom side), 60 nets.

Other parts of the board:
C22, C25: 15pF; C_0603_1608Metric

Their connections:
GND: C22.2, C25.2; also elsewhere on the board
unnamed 28: C22.1; also elsewhere on the board
unnamed 31: C25.1; also elsewhere on the board
